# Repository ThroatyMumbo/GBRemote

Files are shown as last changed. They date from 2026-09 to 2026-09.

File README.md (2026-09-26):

# (WIP) Universal Remote cartridge for Game Boy

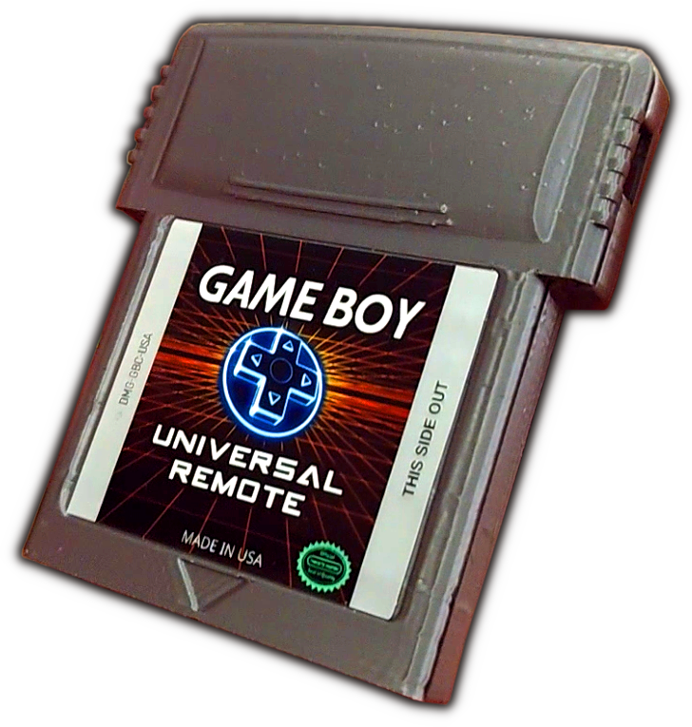
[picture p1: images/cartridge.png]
GB Universal Remote


A cartridge that lets you turn your Game Boy into many different things.
A game controller? A Bluetooth gamepad? A Bluetooth receiver? A tooth brush? Whatever your heart desires!

YouTube video: https://youtu.be/3ZZjWmHPqLs

Both the hardware and core GBC firmware is based on Shilga's Croco Cart:
- https://github.com/shilga/rp2350-gameboy-cartridge-firmware/
- https://github.com/shilga/rp-gameboy-cartridge-hw

## Building

Needs [GBDK-2020](https://github.com/gbdk-2020/gbdk-2020), the [Pico SDK](https://github.com/raspberrypi/pico-sdk) and Python 3.

```
python3 -m venv .venv && .venv/bin/pip install numpy
make -C rom GBDK_HOME=/path/to/gbdk
PICO_SDK_PATH=/path/to/pico-sdk cmake -S firmware -B firmware/build
cmake --build firmware/build
```

The first `make` builds the Game Boy ROM and embeds it in the firmware (`firmware/generated/rom.h`), so rebuild both after changing the ROM.

## Flashing

Hold the BOOTSEL button (`SW2`) while plugging the cartridge's micro-USB port into your computer, then either copy `firmware/build/gbc_controller.uf2` to the drive that appears or run:

```
picotool load -x firmware/build/gbc_controller.uf2
```

## Loading Game Boy ROMs for the Transfer Pak

The N64 driver can act as a Transfer Pak holding a Game Boy ROM stored in the cart's flash. Put the cart in BOOTSEL as above, then:

```
tools/slot.sh 1 game.gbc
```

Pick the game under Controllers → Nintendo 64 → Transfer Pak. Slots 1-6 hold up to 2 MB each and slot 7 up to 1.75 MB; loading one slot leaves the others alone. An optional third argument sets the name shown on the Game Boy.

## Screenshots

| Controller select | Gamepad | Button mapping |
|:---:|:---:|:---:|
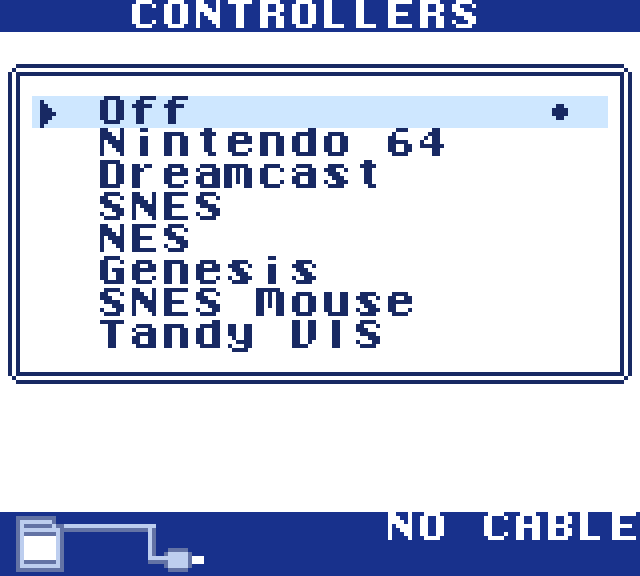
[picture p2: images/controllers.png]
Controller select
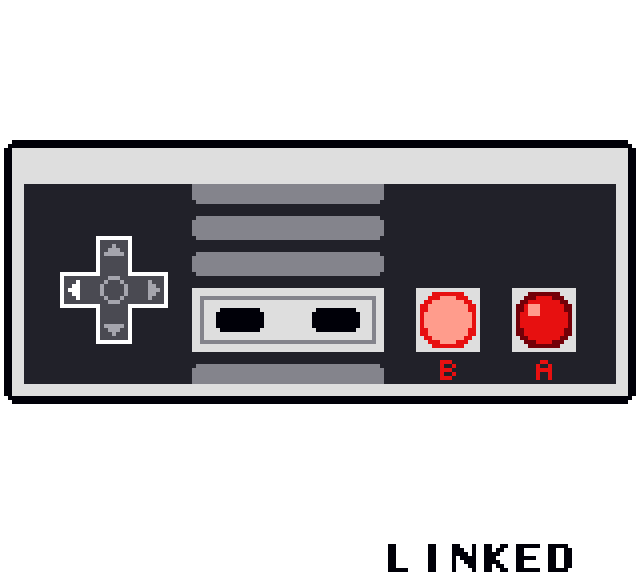
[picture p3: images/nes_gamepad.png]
NES gamepad
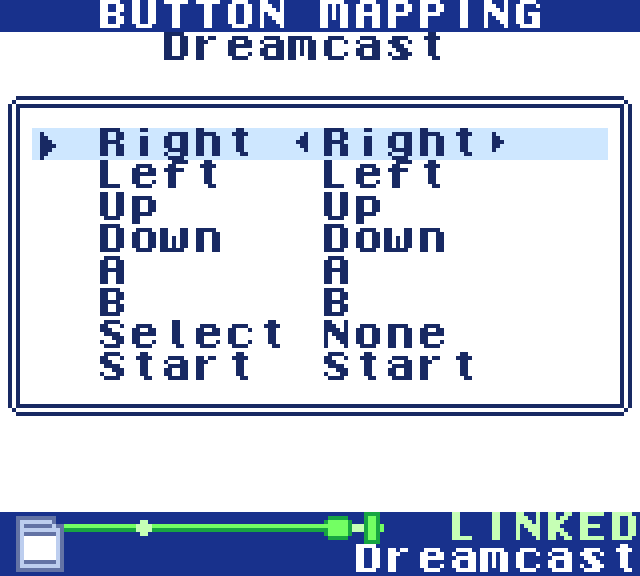
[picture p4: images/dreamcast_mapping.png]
Dreamcast button mapping
|  |  |  |
| **N64 Transfer Pak** | **Dreamcast VMU** | |
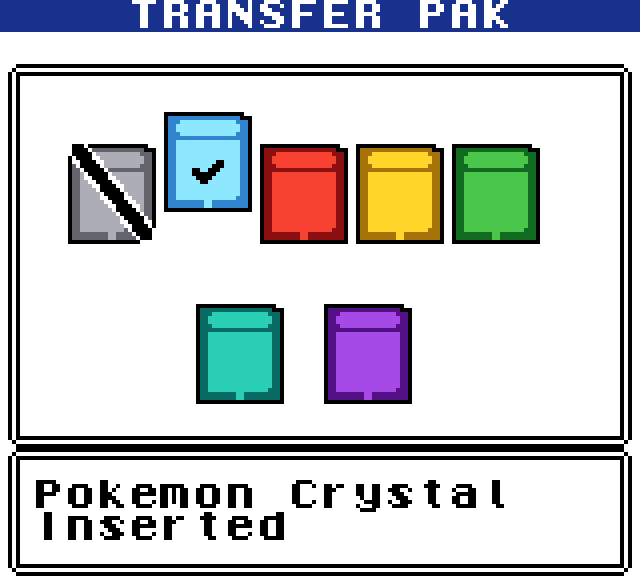
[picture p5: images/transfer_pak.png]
N64 Transfer Pak game select
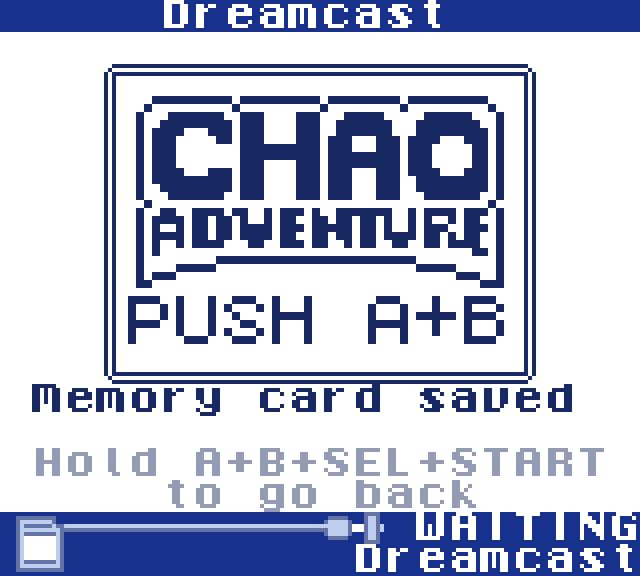
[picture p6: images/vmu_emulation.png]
Chao Adventure on the emulated VMU
|  |  | |

## FAQ

### What the hell is this?

It's a Game Boy cartridge with a bunch of stuff attached to it. USB, Bluetooth, WiFi, IR, even a generic 12-pin controller port via USB-C.

### Is this a flash cart?

Sort of. It can be used as a flash cart, although that isn't the intended purpose. It's more meant for turning a Game Boy Color into a multipurpose remote of sorts.
Plus the onboard flash is 16 MB, which is only enough for like 10 GBC games.

### Where are all those cool demos you showed in the video?

Most of them I probably won't publish since they involve modding existing commercial games, which is messy to maintain in a public repo.
However, original stuff like "Shellack!" will be published at some point when I get a chance to clean it up.

### Does this work on a regular Game Boy? What about Game Boy Advance?

- Regular Game Boy is a maybe. It doesn't physically fit, but you can cleverly bypass this using a Game Shark. However when I tried this myself it just sits on a blank screen. Haven't troubleshooted this problem.
- It does work on a Game Boy Advance

### Where do I buy this?

You can't, at least not directly. This repo contains the production files for the cartridge and adapter PCBs that you can send off to your favorite PCB manufacturing site, but I warn you it'll likely be very expensive (~$500+). Getting just two of these cartridges + 10 adapters made took a couple weeks and lots of back and forth with JLCPCB. Not to mention the tedium of wiring all those controller adapters. I wouldn't recommend it unless you have time and money to burn.

### Will you sell these at some point?

Maybe? Like every project of mine, this is really more of a novelty than something that's practically useful, so I don't see myself ordering hundreds of these and selling them on Ko-fi anytime soon. More likely a very limited run as some special merch or something.

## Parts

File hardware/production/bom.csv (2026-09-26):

Designator | Footprint | Quantity | Value | LCSC Part #
C1, C2 | 0402 | 2 | 15pF | C1548
C10, C11, C12, C13, C14, C15, C16, C17, C18, C19, C20, C21, C27, C29, C31, C32, C5, C9 | 0402 | 18 | 100nF | C1525
C22 | 1210 | 1 | 47uF | C2932478
C23, C25 | 0402 | 2 | 1uF | C52923
C24 | 0805 | 1 | 22uF | C45783
C26 | 1210 | 1 | 100uF 10V | C23742
C28 | 1206 | 1 | 47uF | C96123
C3, C4, C6, C7, C8 | 0402 | 5 | 4.7uF | C23733
C30 | 0402 | 1 | 10nF | C15195
D1, D2, D3, D9 | D_SOD-123F | 4 | SM5817PL 20V | C669022
D4, D5, D6 | SOT-23-6 | 3 | SRV05-4 | C13612
D7 | LED_Vishay_VSMB2943SL | 1 | VSMB2943SLX01 | C511094
F1 | 1206 | 1 | 500mA | C2649911
J1 | GameBoy_Cartridge_EdgeConnector | 1 | CartBus
J2 | USB_Micro-B_XKB_U254-051T-4BH83-F2S | 1 | USB micro-B device | C2682231
J3 | USB_C_Receptacle_Amphenol_12401610E4-2A | 1 | 12401610E4#2A | C5119948
J4 | JST_SH_SM06B-SRSS-TB_1x06-1MP_P1.00mm_Horizontal | 1 | DEBUG | C160405
L1 | L_Murata_DFE201610P | 1 | 3.3uH | C42411119
Q1, Q2 | SOT-23 | 2 | CJ2302 | C8548
R1, R26, R3, R31, R9 | 0402 | 5 | 1k | C11702
R10, R33 | 1206 | 2 | 0R1 | C25334
R11 | 0402 | 1 | 10R | C25077
R14, R15 | 0402 | 2 | 27R | C25100
R16, R17, R18, R19, R20, R21, R22, R23, R25 | 0402 | 9 | 100R | C25076
R2, R24, R27, R35, R4, R5, R8 | 0402 | 7 | 10k | C25744
R28 | 1206 | 1 | 22R | C17958
R29, R32 | 0402 | 2 | 100k | C25741
R30 | 0402 | 1 | 0R | C17168
R34 | 0402 | 1 | 470R | C25117
R6, R7 | 0402 | 2 | 33R | C25105
SW2 | SW_SPST_PTS810 | 1 | BOOTSEL | C116501
U1 | QFN-80-1EP_10x10mm_P0.4mm_EP3.4x3.4mm_ThermalVias | 1 | RP2350B | C42415655
U2 | SOIC-8_5.3x5.3mm_P1.27mm | 1 | W25Q128JVSIQ | C97521
U3 | SOIC-8_3.9x4.9mm_P1.27mm | 1 | APS6404L-3SQR-SN | C5333729
U4 | SOT-23-5 | 1 | AP2112K-3.3 | C51118
U5 | SOT-666 | 1 | USBLC6-2P6 | C15999
U6 | SOT-23-6 | 1 | TPS22917DBV | C2681320
U7 | RaspberryPi_RM2 | 1 | RMC20452T | C49451547
Y1 | Crystal_SMD_3225-4Pin_3.2x2.5mm | 1 | 12MHz | C20625731

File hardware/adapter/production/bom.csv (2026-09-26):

Designator | Footprint | Quantity | Value | LCSC Part #
J1 | USB_C_Plug_XUNPU_TYPEC-950-ARP24 | 1 | TYPEC-950-ARP24 | C2895017
J2 | WireTerminal_1x12_Staggered | 1 | Wire terminals

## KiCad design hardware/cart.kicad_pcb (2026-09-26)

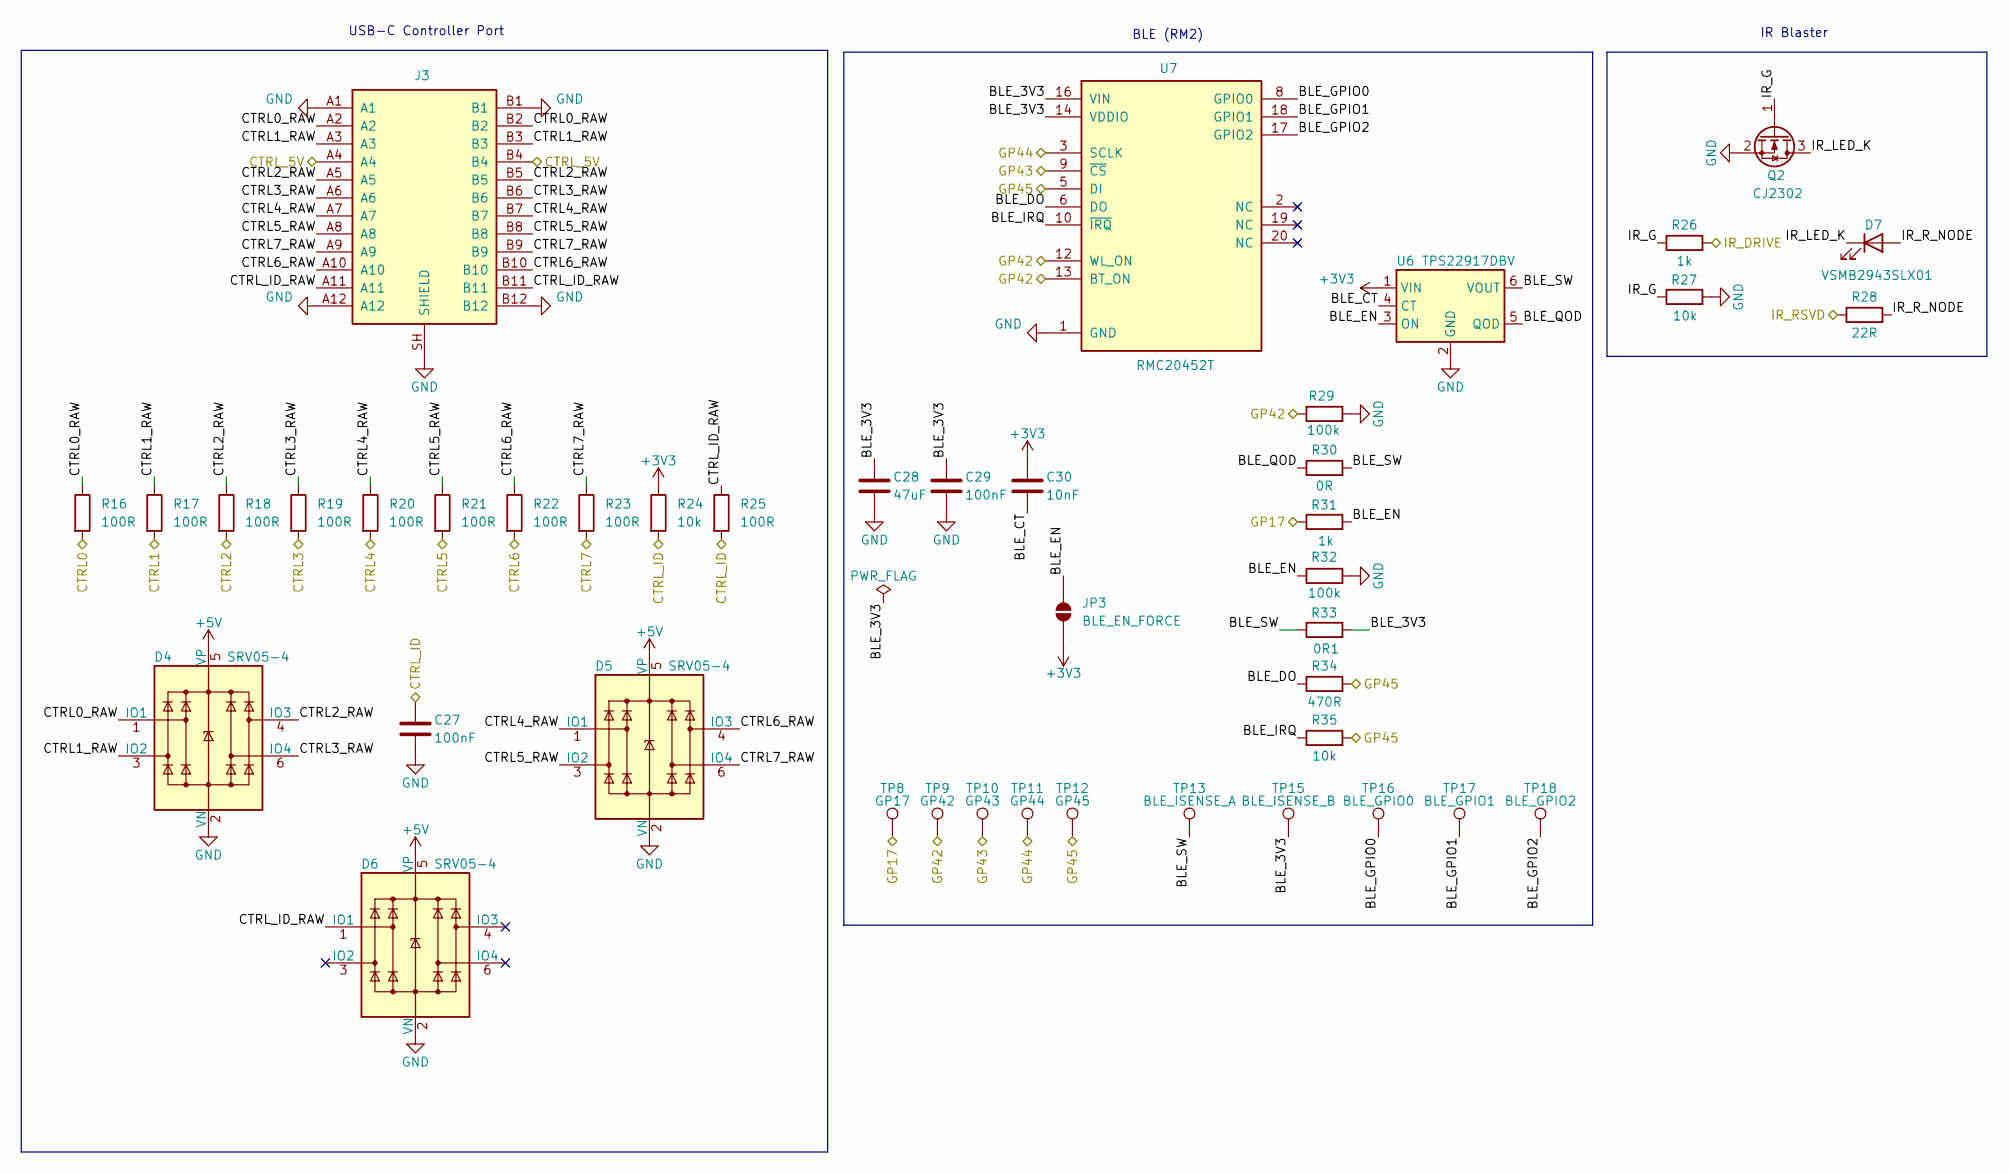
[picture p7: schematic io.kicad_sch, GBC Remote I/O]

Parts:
C27, C29: 100nF; C_0402_1005Metric; LCSC C1525
C28: 47uF; C_1206_3216Metric; LCSC C96123
C30: 10nF; C_0402_1005Metric; LCSC C15195
D4, D5, D6: SRV05-4; SOT-23-6; LCSC C13612
D7: VSMB2943SLX01; LED_Vishay_VSMB2943SL; LCSC C511094
J3: 12401610E4#2A; USB_C_Receptacle_Amphenol_12401610E4-2A; LCSC C5119948
JP3: BLE_EN_FORCE; SolderJumper-2_P1.3mm_Open_RoundedPad1.0x1.5mm
Q2: CJ2302; SOT-23; LCSC C8548
R16, R17, R18, R19, R20, R21, R22, R23, R25: 100R; R_0402_1005Metric; LCSC C25076
R24, R27, R35: 10k; R_0402_1005Metric; LCSC C25744
R26, R31: 1k; R_0402_1005Metric; LCSC C11702
R28: 22R; R_1206_3216Metric; LCSC C17958
R29, R32: 100k; R_0402_1005Metric; LCSC C25741
R30: 0R; R_0402_1005Metric; LCSC C17168
R33: 0R1; R_1206_3216Metric; LCSC C25334
R34: 470R; R_0402_1005Metric; LCSC C25117
TP8: GP17; TestPoint_Pad_D1.0mm
TP9: GP42; TestPoint_Pad_D1.0mm
TP10: GP43; TestPoint_Pad_D1.0mm
TP11: GP44; TestPoint_Pad_D1.0mm
TP12: GP45; TestPoint_Pad_D1.0mm
TP13: BLE_ISENSE_A; TestPoint_Pad_D1.0mm
TP15: BLE_ISENSE_B; TestPoint_Pad_D1.0mm
TP16: BLE_GPIO0; TestPoint_Pad_D1.0mm
TP17: BLE_GPIO1; TestPoint_Pad_D1.0mm
TP18: BLE_GPIO2; TestPoint_Pad_D1.0mm
U6: TPS22917DBV; SOT-23-6; LCSC C2681320
U7: RMC20452T; RaspberryPi_RM2; LCSC C49451547

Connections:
+3V3: C30.1, JP3.1 (A), R24.1, U6.1 (VIN); also elsewhere on the board
+5V: D4.5 (VP), D5.5 (VP), D6.5 (VP); also elsewhere on the board
/CTRL0: R16.2; also elsewhere on the board
/CTRL1: R17.2; also elsewhere on the board
/CTRL2: R18.2; also elsewhere on the board
/CTRL3: R19.2; also elsewhere on the board
/CTRL4: R20.2; also elsewhere on the board
/CTRL5: R21.2; also elsewhere on the board
/CTRL6: R22.2; also elsewhere on the board
/CTRL7: R23.2; also elsewhere on the board
/CTRL_5V: J3.A4, J3.B4; also elsewhere on the board
/CTRL_ID: C27.1, R24.2, R25.2; also elsewhere on the board
/Controller Port, IR, BLE/BLE_3V3: C28.1, C29.1, R33.2, TP15.1, U7.14 (VDDIO), U7.16 (VIN)
/Controller Port, IR, BLE/BLE_CT: C30.2, U6.4 (CT)
/Controller Port, IR, BLE/BLE_DO: R34.1, U7.6 (DO)
/Controller Port, IR, BLE/BLE_EN: JP3.2 (B), R31.2, R32.1, U6.3 (ON)
/Controller Port, IR, BLE/BLE_GPIO0: TP16.1, U7.8 (GPIO0)
/Controller Port, IR, BLE/BLE_GPIO1: TP17.1, U7.18 (GPIO1)
/Controller Port, IR, BLE/BLE_GPIO2: TP18.1, U7.17 (GPIO2)
/Controller Port, IR, BLE/BLE_IRQ: R35.1, U7.10 (~IRQ)
/Controller Port, IR, BLE/BLE_QOD: R30.1, U6.5 (QOD)
/Controller Port, IR, BLE/BLE_SW: R30.2, R33.1, TP13.1, U6.6 (VOUT)
/Controller Port, IR, BLE/CTRL0_RAW: D4.1 (IO1), J3.A2, J3.B2, R16.1
/Controller Port, IR, BLE/CTRL1_RAW: D4.3 (IO2), J3.A3, J3.B3, R17.1
/Controller Port, IR, BLE/CTRL2_RAW: D4.4 (IO3), J3.A5, J3.B5, R18.1
/Controller Port, IR, BLE/CTRL3_RAW: D4.6 (IO4), J3.A6, J3.B6, R19.1
/Controller Port, IR, BLE/CTRL4_RAW: D5.1 (IO1), J3.A7, J3.B7, R20.1
/Controller Port, IR, BLE/CTRL5_RAW: D5.3 (IO2), J3.A8, J3.B8, R21.1
/Controller Port, IR, BLE/CTRL6_RAW: D5.4 (IO3), J3.A10, J3.B10, R22.1
/Controller Port, IR, BLE/CTRL7_RAW: D5.6 (IO4), J3.A9, J3.B9, R23.1
/Controller Port, IR, BLE/CTRL_ID_RAW: D6.1 (IO1), J3.A11, J3.B11, R25.1
/Controller Port, IR, BLE/IR_G: Q2.1 (G), R26.1, R27.1
/Controller Port, IR, BLE/IR_LED_K: D7.1 (K), Q2.3 (D)
/Controller Port, IR, BLE/IR_R_NODE: D7.2 (A), R28.2
/GP17: R31.1, TP8.1; also elsewhere on the board
/GP42: R29.1, TP9.1, U7.12 (WL_ON), U7.13 (BT_ON); also elsewhere on the board
/GP43: TP10.1, U7.9 (~CS); also elsewhere on the board
/GP44: TP11.1, U7.3 (SCLK); also elsewhere on the board
/GP45: R34.2, R35.2, TP12.1, U7.5 (DI); also elsewhere on the board
/IR_DRIVE: R26.2; also elsewhere on the board
/IR_RSVD: R28.1; also elsewhere on the board
GND: C27.2, C28.2, C29.2, D4.2 (VN), D5.2 (VN), D6.2 (VN), J3.A1, J3.A12, J3.B1, J3.B12, J3.SH (SHIELD), Q2.2 (S), R27.2, R29.2, R32.2, U6.2 (GND), U7.1 (GND), U7.4 (GND), U7.7 (GND), U7.11 (GND), U7.15 (GND), U7.21 (GND); also elsewhere on the board

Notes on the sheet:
IR Blaster
BLE (RM2)
USB-C Controller Port

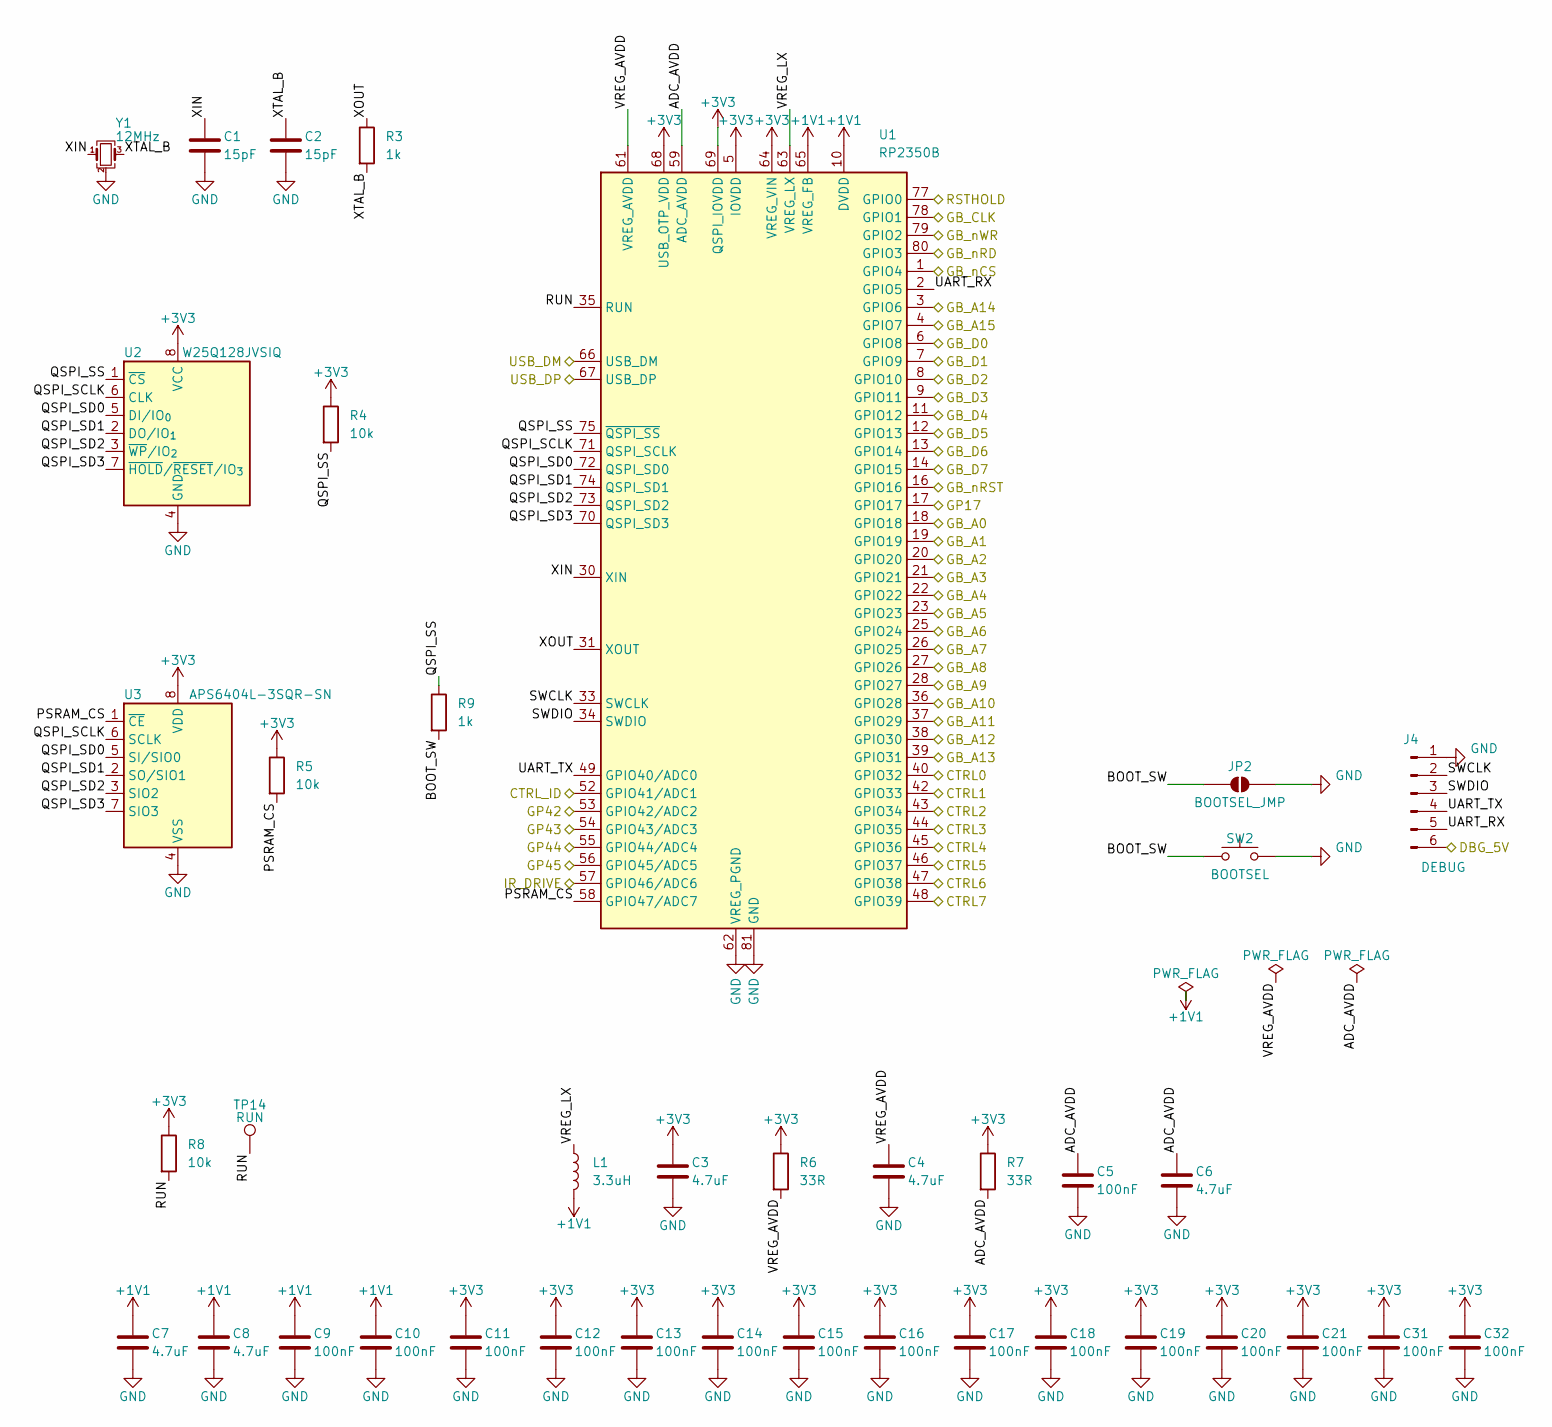
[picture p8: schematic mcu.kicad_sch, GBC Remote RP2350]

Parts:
C1, C2: 15pF; C_0402_1005Metric; LCSC C1548
C3, C4, C6, C7, C8: 4.7uF; C_0402_1005Metric; LCSC C23733
C5, C9, C10, C11, C12, C13, C14, C15, C16, C17, C18, C19, C20, C21, C31, C32: 100nF; C_0402_1005Metric; LCSC C1525
J4: DEBUG; JST_SH_SM06B-SRSS-TB_1x06-1MP_P1.00mm_Horizontal; LCSC C160405
JP2: BOOTSEL_JMP; SolderJumper-2_P1.3mm_Open_RoundedPad1.0x1.5mm
L1: 3.3uH; L_Murata_DFE201610P; LCSC C42411119
R3, R9: 1k; R_0402_1005Metric; LCSC C11702
R4, R5, R8: 10k; R_0402_1005Metric; LCSC C25744
R6, R7: 33R; R_0402_1005Metric; LCSC C25105
SW2: BOOTSEL; SW_SPST_PTS810; LCSC C116501
TP14: RUN; TestPoint_Pad_D1.0mm
U1: RP2350B; QFN-80-1EP_10x10mm_P0.4mm_EP3.4x3.4mm_ThermalVias; LCSC C42415655
U2: W25Q128JVSIQ; SOIC-8_5.3x5.3mm_P1.27mm; LCSC C97521
U3: APS6404L-3SQR-SN; SOIC-8_3.9x4.9mm_P1.27mm; LCSC C5333729
Y1: 12MHz; Crystal_SMD_3225-4Pin_3.2x2.5mm; LCSC C20625731

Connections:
+1V1: C7.1, C8.1, C9.1, C10.1, L1.2, U1.10 (DVDD), U1.32 (DVDD), U1.51 (DVDD), U1.65 (VREG_FB); also elsewhere on the board
+3V3: C3.1, C11.1, C12.1, C13.1, C14.1, C15.1, C16.1, C17.1, C18.1, C19.1, C20.1, C21.1, C31.1, C32.1, R4.1, R5.1, R6.1, R7.1, R8.1, U1.5 (IOVDD), U1.15 (IOVDD), U1.24 (IOVDD), U1.29 (IOVDD), U1.41 (IOVDD), U1.50 (IOVDD), U1.60 (IOVDD), U1.64 (VREG_VIN), U1.68 (USB_OTP_VDD), U1.69 (QSPI_IOVDD), U1.76 (IOVDD), U2.8 (VCC), U3.8 (VDD); also elsewhere on the board
/CTRL0: U1.40 (GPIO32); also elsewhere on the board
/CTRL1: U1.42 (GPIO33); also elsewhere on the board
/CTRL2: U1.43 (GPIO34); also elsewhere on the board
/CTRL3: U1.44 (GPIO35); also elsewhere on the board
/CTRL4: U1.45 (GPIO36); also elsewhere on the board
/CTRL5: U1.46 (GPIO37); also elsewhere on the board
/CTRL6: U1.47 (GPIO38); also elsewhere on the board
/CTRL7: U1.48 (GPIO39); also elsewhere on the board
/CTRL_ID: U1.52 (GPIO41/ADC1); also elsewhere on the board
/DBG_5V: J4.6; also elsewhere on the board
/GB_A0: U1.18 (GPIO18); also elsewhere on the board
/GB_A1: U1.19 (GPIO19); also elsewhere on the board
/GB_A2: U1.20 (GPIO20); also elsewhere on the board
/GB_A3: U1.21 (GPIO21); also elsewhere on the board
/GB_A4: U1.22 (GPIO22); also elsewhere on the board
/GB_A5: U1.23 (GPIO23); also elsewhere on the board
/GB_A6: U1.25 (GPIO24); also elsewhere on the board
/GB_A7: U1.26 (GPIO25); also elsewhere on the board
/GB_A8: U1.27 (GPIO26); also elsewhere on the board
/GB_A9: U1.28 (GPIO27); also elsewhere on the board
/GB_A10: U1.36 (GPIO28); also elsewhere on the board
/GB_A11: U1.37 (GPIO29); also elsewhere on the board
/GB_A12: U1.38 (GPIO30); also elsewhere on the board
/GB_A13: U1.39 (GPIO31); also elsewhere on the board
/GB_A14: U1.3 (GPIO6); also elsewhere on the board
/GB_A15: U1.4 (GPIO7); also elsewhere on the board
/GB_CLK: U1.78 (GPIO1); also elsewhere on the board
/GB_D0: U1.6 (GPIO8); also elsewhere on the board
/GB_D1: U1.7 (GPIO9); also elsewhere on the board
/GB_D2: U1.8 (GPIO10); also elsewhere on the board
/GB_D3: U1.9 (GPIO11); also elsewhere on the board
/GB_D4: U1.11 (GPIO12); also elsewhere on the board
/GB_D5: U1.12 (GPIO13); also elsewhere on the board
/GB_D6: U1.13 (GPIO14); also elsewhere on the board
/GB_D7: U1.14 (GPIO15); also elsewhere on the board
/GB_nCS: U1.1 (GPIO4); also elsewhere on the board
/GB_nRD: U1.80 (GPIO3); also elsewhere on the board
/GB_nRST: U1.16 (GPIO16); also elsewhere on the board
/GB_nWR: U1.79 (GPIO2); also elsewhere on the board
/GP17: U1.17 (GPIO17); also elsewhere on the board
/GP42: U1.53 (GPIO42/ADC2); also elsewhere on the board
/GP43: U1.54 (GPIO43/ADC3); also elsewhere on the board
/GP44: U1.55 (GPIO44/ADC4); also elsewhere on the board
/GP45: U1.56 (GPIO45/ADC5); also elsewhere on the board
/IR_DRIVE: U1.57 (GPIO46/ADC6); also elsewhere on the board
/MCU/ADC_AVDD: C5.1, C6.1, R7.2, U1.59 (ADC_AVDD)
/MCU/BOOT_SW: JP2.1 (A), R9.2, SW2.1
/MCU/PSRAM_CS: R5.2, U1.58 (GPIO47/ADC7), U3.1 (~CE)
/MCU/QSPI_SCLK: U1.71 (QSPI_SCLK), U2.6 (CLK), U3.6 (SCLK)
/MCU/QSPI_SD0: U1.72 (QSPI_SD0), U2.5 (DI/IO_{0}), U3.5 (SI/SIO0)
/MCU/QSPI_SD1: U1.74 (QSPI_SD1), U2.2 (DO/IO_{1}), U3.2 (SO/SIO1)
/MCU/QSPI_SD2: U1.73 (QSPI_SD2), U2.3 (~WP/IO_{2}), U3.3 (SIO2)
/MCU/QSPI_SD3: U1.70 (QSPI_SD3), U2.7 (~HOLD/~RESET/IO_{3}), U3.7 (SIO3)
/MCU/QSPI_SS: R4.2, R9.1, U1.75 (~QSPI_SS), U2.1 (~CS)
/MCU/RUN: R8.2, TP14.1, U1.35 (RUN)
/MCU/SWCLK: J4.2, U1.33 (SWCLK)
/MCU/SWDIO: J4.3, U1.34 (SWDIO)
/MCU/UART_RX: J4.5, U1.2 (GPIO5)
/MCU/UART_TX: J4.4, U1.49 (GPIO40/ADC0)
/MCU/VREG_AVDD: C4.1, R6.2, U1.61 (VREG_AVDD)
/MCU/VREG_LX: L1.1, U1.63 (VREG_LX)
/MCU/XIN: C1.1, U1.30 (XIN), Y1.1
/MCU/XOUT: R3.1, U1.31 (XOUT)
/MCU/XTAL_B: C2.1, R3.2, Y1.3
/RSTHOLD: U1.77 (GPIO0); also elsewhere on the board
/USB_DM: U1.66 (USB_DM); also elsewhere on the board
/USB_DP: U1.67 (USB_DP); also elsewhere on the board
GND: C1.2, C2.2, C3.2, C4.2, C5.2, C6.2, C7.2, C8.2, C9.2, C10.2, C11.2, C12.2, C13.2, C14.2, C15.2, C16.2, C17.2, C18.2, C19.2, C20.2, C21.2, C31.2, C32.2, J4.1, JP2.2 (B), SW2.2, U1.62 (VREG_PGND), U1.81 (GND), U2.4 (GND), U3.4 (VSS), Y1.2 (G), Y1.4 (G); also elsewhere on the board

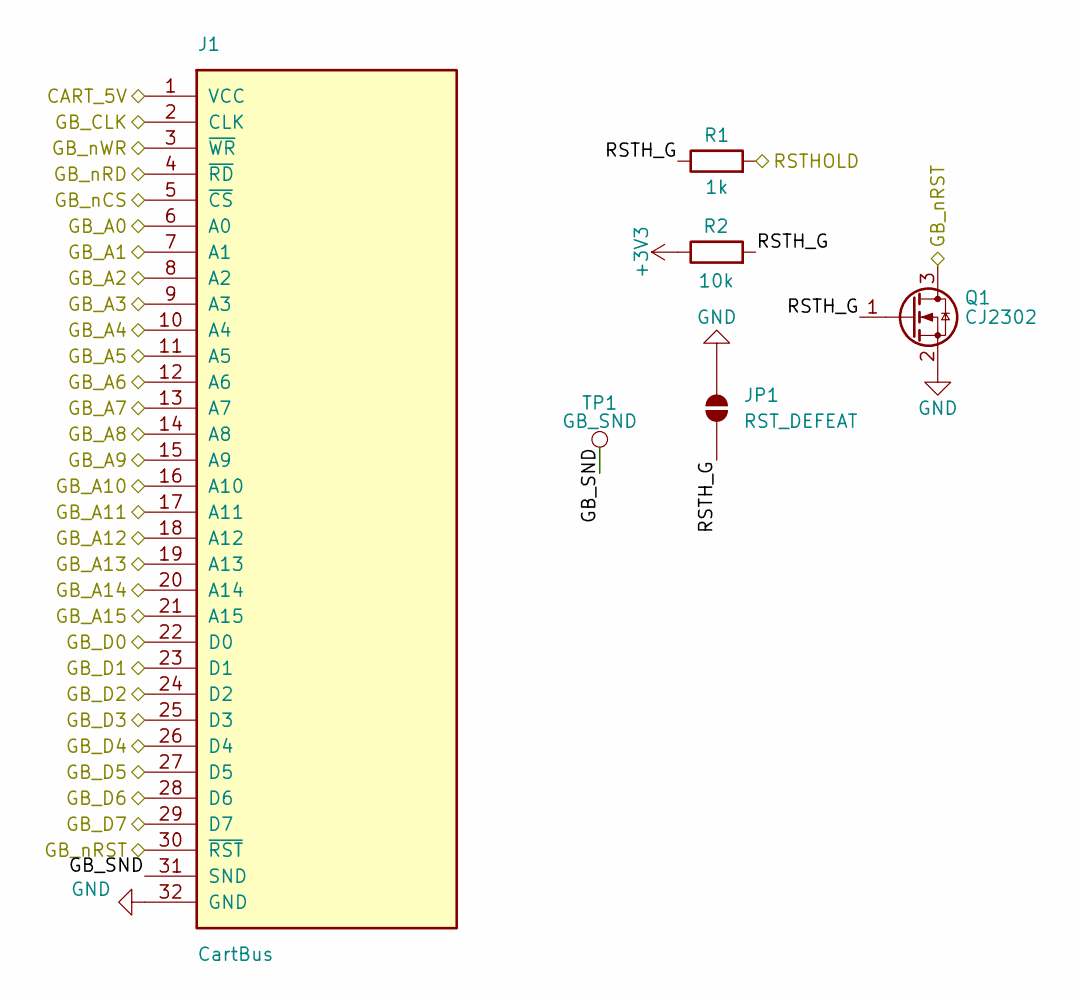
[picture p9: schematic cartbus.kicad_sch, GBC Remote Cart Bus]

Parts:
J1: CartBus; GameBoy_Cartridge_EdgeConnector
JP1: RST_DEFEAT; SolderJumper-2_P1.3mm_Open_RoundedPad1.0x1.5mm
Q1: CJ2302; SOT-23; LCSC C8548
R1: 1k; R_0402_1005Metric; LCSC C11702
R2: 10k; R_0402_1005Metric; LCSC C25744
TP1: GB_SND; TestPoint_Pad_D1.0mm

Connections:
+3V3: R2.1; also elsewhere on the board
/CART_5V: J1.1 (VCC); also elsewhere on the board
/Cart Bus/GB_SND: J1.31 (SND), TP1.1
/Cart Bus/RSTH_G: JP1.1 (A), Q1.1 (G), R1.1, R2.2
/GB_A0: J1.6 (A0); also elsewhere on the board
/GB_A1: J1.7 (A1); also elsewhere on the board
/GB_A2: J1.8 (A2); also elsewhere on the board
/GB_A3: J1.9 (A3); also elsewhere on the board
/GB_A4: J1.10 (A4); also elsewhere on the board
/GB_A5: J1.11 (A5); also elsewhere on the board
/GB_A6: J1.12 (A6); also elsewhere on the board
/GB_A7: J1.13 (A7); also elsewhere on the board
/GB_A8: J1.14 (A8); also elsewhere on the board
/GB_A9: J1.15 (A9); also elsewhere on the board
/GB_A10: J1.16 (A10); also elsewhere on the board
/GB_A11: J1.17 (A11); also elsewhere on the board
/GB_A12: J1.18 (A12); also elsewhere on the board
/GB_A13: J1.19 (A13); also elsewhere on the board
/GB_A14: J1.20 (A14); also elsewhere on the board
/GB_A15: J1.21 (A15); also elsewhere on the board
/GB_CLK: J1.2 (CLK); also elsewhere on the board
/GB_D0: J1.22 (D0); also elsewhere on the board
/GB_D1: J1.23 (D1); also elsewhere on the board
/GB_D2: J1.24 (D2); also elsewhere on the board
/GB_D3: J1.25 (D3); also elsewhere on the board
/GB_D4: J1.26 (D4); also elsewhere on the board
/GB_D5: J1.27 (D5); also elsewhere on the board
/GB_D6: J1.28 (D6); also elsewhere on the board
/GB_D7: J1.29 (D7); also elsewhere on the board
/GB_nCS: J1.5 (~CS); also elsewhere on the board
/GB_nRD: J1.4 (~RD); also elsewhere on the board
/GB_nRST: J1.30 (~RST), Q1.3 (D); also elsewhere on the board
/GB_nWR: J1.3 (~WR); also elsewhere on the board
/RSTHOLD: R1.2; also elsewhere on the board
GND: J1.32 (GND), JP1.2 (B), Q1.2 (S); also elsewhere on the board

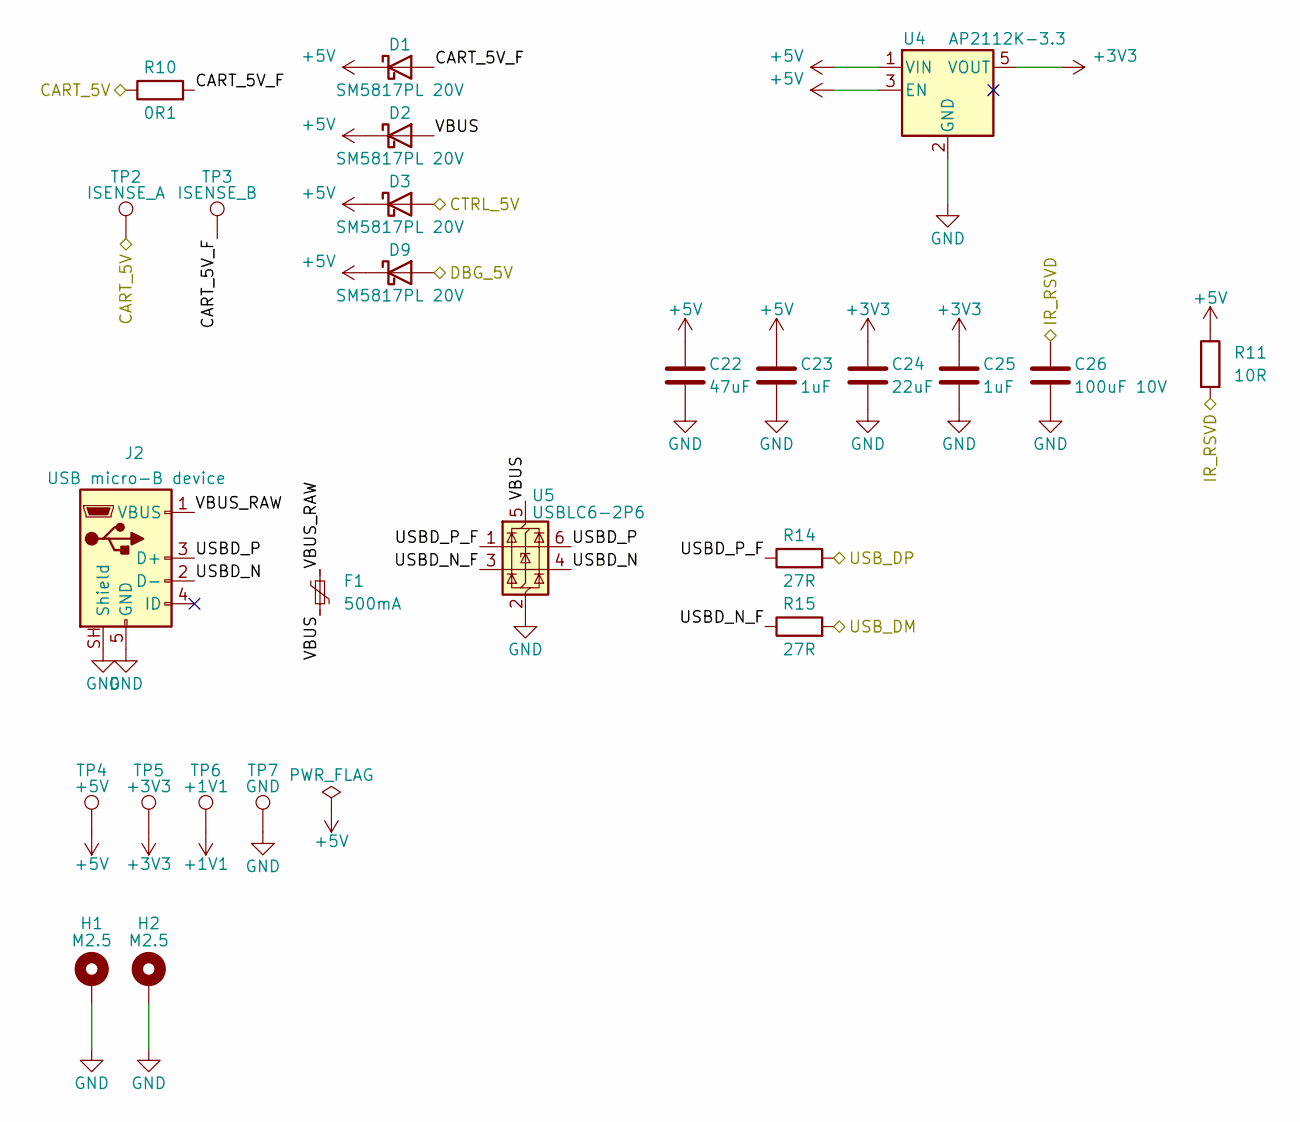
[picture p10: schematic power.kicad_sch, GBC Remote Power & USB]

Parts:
C22: 47uF; C_1210_3225Metric; LCSC C2932478
C23, C25: 1uF; C_0402_1005Metric; LCSC C52923
C24: 22uF; C_0805_2012Metric; LCSC C45783
C26: 100uF 10V; C_1210_3225Metric; LCSC C23742
D1, D2, D3, D9: SM5817PL 20V; D_SOD-123F; LCSC C669022
F1: 500mA; Fuse_1206_3216Metric; LCSC C2649911
H1, H2: M2.5; MountingHole_2.7mm_M2.5_Pad
J2: USB micro-B device; USB_Micro-B_XKB_U254-051T-4BH83-F2S; LCSC C2682231
R10: 0R1; R_1206_3216Metric; LCSC C25334
R11: 10R; R_0402_1005Metric; LCSC C25077
R14, R15: 27R; R_0402_1005Metric; LCSC C25100
TP2: ISENSE_A; TestPoint_Pad_D1.0mm
TP3: ISENSE_B; TestPoint_Pad_D1.0mm
TP4: +5V; TestPoint_Pad_D1.0mm
TP5: +3V3; TestPoint_Pad_D1.0mm
TP6: +1V1; TestPoint_Pad_D1.0mm
TP7: GND; TestPoint_Pad_D1.0mm
U4: AP2112K-3.3; SOT-23-5; LCSC C51118
U5: USBLC6-2P6; SOT-666; LCSC C15999

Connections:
+1V1: TP6.1; also elsewhere on the board
+3V3: C24.1, C25.1, TP5.1, U4.5 (VOUT); also elsewhere on the board
+5V: C22.1, C23.1, D1.1 (K), D2.1 (K), D3.1 (K), D9.1 (K), R11.1, TP4.1, U4.1 (VIN), U4.3 (EN); also elsewhere on the board
/CART_5V: R10.1, TP2.1; also elsewhere on the board
/CTRL_5V: D3.2 (A); also elsewhere on the board
/DBG_5V: D9.2 (A); also elsewhere on the board
/IR_RSVD: C26.1, R11.2; also elsewhere on the board
/Power and USB/CART_5V_F: D1.2 (A), R10.2, TP3.1
/Power and USB/USBD_N: J2.2 (D-), U5.4 (I/O2)
/Power and USB/USBD_N_F: R15.1, U5.3 (I/O2)
/Power and USB/USBD_P: J2.3 (D+), U5.6 (I/O1)
/Power and USB/USBD_P_F: R14.1, U5.1 (I/O1)
/Power and USB/VBUS: D2.2 (A), F1.2, U5.5 (VBUS)
/Power and USB/VBUS_RAW: F1.1, J2.1 (VBUS)
/USB_DM: R15.2; also elsewhere on the board
/USB_DP: R14.2; also elsewhere on the board
GND: C22.2, C23.2, C24.2, C25.2, C26.2, H1.1, H2.1, J2.5 (GND), J2.SH (Shield), TP7.1, U4.2 (GND), U5.2 (GND); also elsewhere on the board

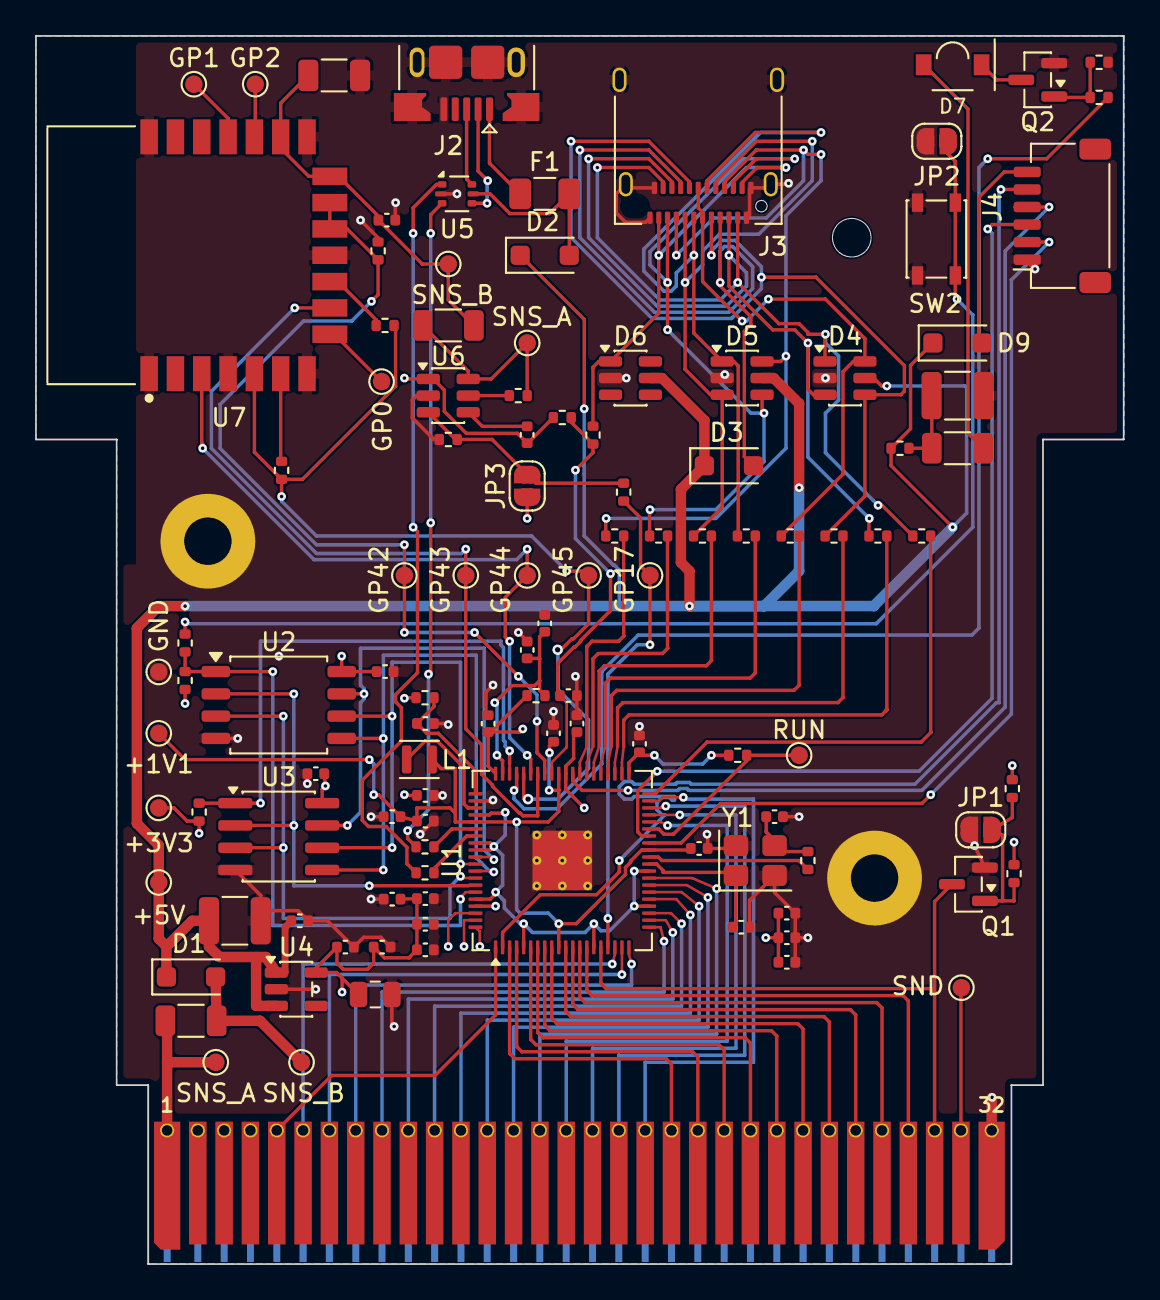
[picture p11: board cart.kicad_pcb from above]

Board: 4 copper layers, 62.0 x 70.0 mm, 113 parts (0 on the bottom side), 105 nets.

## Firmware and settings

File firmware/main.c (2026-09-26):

// GBC controller cart: serves the menu ROM from SRAM (cartserve.c), decodes the cart-bus mailbox on
// core0 in run_bus(), and runs the resident pad driver on core1 (driver_core.c).

#include "pico/stdlib.h"
#include "hardware/clocks.h"
#include "hardware/pio.h"
#include "hardware/flash.h"
#include "hardware/sync.h"
#include "hardware/structs/sio.h"
#include "hardware/timer.h"
#include <stdio.h>
#include <string.h>

#include "pinmap.h"
#include "cartserve.h"
#include "psram.h"
#include "rom.h"                // generated by run.sh: gb_rom[GB_ROM_BANKS][16384], in flash
#include "cart_mbc.h"
#include "config_map.h"
#include "ctrl.h"
#include "cable_id.h"
#include "driver_core.h"
#include "pad_catalog.h"
#include "pad_mapinfo.h"
#include "romstore.h"
#include "vmu_stage.h"
#include "vmu_store.h"
#include "vmu_run.h"
#include "vmu_fb.h"
#include "padart.h"
#include "flash_burn.h"

#define FW_VERSION 1

_Static_assert(GB_ROM_BANKS >= 2 && GB_ROM_BANKS <= 16, "every bank is resident: 2-16 banks");

// Banks 0 and 1 are cartserve's own: cs_seed() lands in 0, and 1 is the VMU/art window.
static uint8_t __attribute__((aligned(0x4000))) g_banks[GB_ROM_BANKS > 2 ? GB_ROM_BANKS - 2 : 1][0x4000];
static uint8_t *g_bank_ptr[GB_ROM_BANKS];

// GB -> firmware: writes to $6000+n, n from A0-A2, latched for free by write_capture.
#define MBOX_REGION   0x6000
enum { MBOX_BTN = 0, MBOX_MODE = 1, MBOX_CFG_IDX = 2, MBOX_CFG_VAL = 3, MBOX_COMMIT = 4 };

// firmware -> GB: plain bytes of the served bank 0, rewritten under the console.
#define STATUS_ADDR    0x0010
#define VERSION_ADDR   0x0011
#define ID_ADDR        0x0012   // adapter slot from the cable ID ladder (ADAPT_*)
#define DIAG_ADDR      0x0013   // driver error code, so the ROM can say why nothing is driven
// The PROTO_SEL echo is no proof a driver started; these are what core1 owns and when it acted.
#define ACTIVE_ADDR    0x0014   // PROTO_* of the resident driver, PROTO_NONE if nothing is driven
#define APPLYSEQ_ADDR  0x0015   // low byte of the drv_apply() counter
// The Visual Memory. SEQ is bumped after a whole frame is in place, so the ROM never blits mid-write.
#define VMU_SEQ_ADDR   0x0016
#define VMU_STAT_ADDR  0x0017
#define VMU_SAVES_ADDR 0x0018
// The controller picture staged at $4600 (padart.h). PROTO says whose it is, SEQ that it is whole.
#define ART_SEQ_ADDR   0x0019
#define ART_PROTO_ADDR 0x001a
// pad.h's PAD_* bits 0-23 after map_apply(), low byte first: what core1 drives, not what the GB pressed.
#define PAD_LIVE_ADDR  0x001b
#define PAD_LIVE_SEQ   0x001e   // poked last; the three data bytes are separate pokes and can tear

#define VMU_ST_CARD    0x01     // a card is live
#define VMU_ST_DIRTY   0x02     // writes the flash copy does not have yet
#define VMU_ST_SAVING  0x04     // a writeback is in flight
#define VMU_ST_FRAME   0x08     // the console has drawn to the LCD this session
#define CFG_MIRROR     0x0200   // CFG_LEN bytes, config_map.h
#define CATALOG_ADDR   0x0300   // driver catalog, pad_catalog.h. Seeded once at boot, never rewritten.

#define ST_ALIVE       0x01     // firmware up and serving
#define ST_LINK_UP     0x02     // transport connected
#define ST_FORCE_CFG   0x80     // escape hatch: ROM must leave capture mode

enum { MODE_CONFIG = 0, MODE_CAPTURE = 1 };

static uint8_t  g_config[CFG_LEN];
static volatile uint8_t  g_buttons, g_mode, g_status = ST_ALIVE;
static volatile uint8_t  g_cfg_idx, g_cfg_class, g_adapter, g_diag, g_active, g_aseq;
static volatile bool     g_cfg_dirty, g_commit_req, g_btn_pending;
static volatile uint32_t g_btn_seq, g_wr_count, g_mbox_writes, g_gb_runs;
static uint32_t g_ps_size;


static void publish_status(void) { cs_poke(STATUS_ADDR, g_status); }

static uint8_t g_vmu_stat = VMU_ST_CARD, g_vmu_saves;

// On change, like ACTIVE/APPLYSEQ: the ROM polls these every pass and a poke costs a bus cycle.
static void publish_vmu(void) {
    const vmu_stage_t *s = vmu_stage();
    uint8_t st = (uint8_t)(VMU_ST_CARD
                 | (s->writes != s->saved_writes ? VMU_ST_DIRTY : 0)
                 | (vmu_store_busy() ? VMU_ST_SAVING : 0)
                 | (s->lcd_frames ? VMU_ST_FRAME : 0));

    if (st != g_vmu_stat)              { g_vmu_stat = st;  cs_poke(VMU_STAT_ADDR, st); }
    if ((uint8_t)s->saves != g_vmu_saves) {
        g_vmu_saves = (uint8_t)s->saves;
        cs_poke(VMU_SAVES_ADDR, g_vmu_saves);
    }
}

// On change only, like publish_vmu(): a poke costs a bus cycle and the ROM polls these every pass.
static uint32_t g_pad_live = 0xffffffffU;
static uint8_t  g_pad_live_seq;

static void publish_pad_live(void) {
    uint32_t b = drv_pad_live() & 0xffffffU;
    if (b == g_pad_live) { return; }
    for (unsigned i = 0; i < 3; i++) {
        if (((b ^ g_pad_live) >> (8 * i)) & 0xffU) {
            cs_poke((uint16_t)(PAD_LIVE_ADDR + i), (uint8_t)(b >> (8 * i)));
        }
    }
    g_pad_live = b;
    cs_poke(PAD_LIVE_SEQ, ++g_pad_live_seq);            // after the data, always
}

static void publish_config(void) {
    for (uint32_t i = 0; i < CFG_LEN; i++) { cs_poke(CFG_MIRROR + i, g_config[i]); }
}

// A known cable overrides the selected protocol in g_config itself, so the mirror tells the menu.
static bool cable_select(void) {
#ifdef BENCH_PROTO
    return false;
#else
    uint8_t p = cable_id_proto(g_adapter, g_config[CFG_PROTO_SEL]);
    if (p == g_config[CFG_PROTO_SEL]) { return false; }
    g_config[CFG_PROTO_SEL] = p;
    return true;
#endif
}

// Config lives in the last flash sector. Erasing it live stalls core0, never the SRAM serve path.
#define CFG_FLASH_OFF (PICO_FLASH_SIZE_BYTES - FLASH_SECTOR_SIZE)
#define CFG_MAGIC     0x43474243u
#define CFG_PAGE      (2 * FLASH_PAGE_SIZE)   // magic + CFG_LEN rounded up to a programmable multiple

static void config_load(void) {
    const uint8_t *p = (const uint8_t *)(XIP_BASE + CFG_FLASH_OFF);
    uint32_t magic;
    memcpy(&magic, p, sizeof magic);
    if (magic == CFG_MAGIC) {
        memcpy(g_config, p + 4, CFG_LEN);
    } else {
        memset(g_config, 0xff, CFG_LEN);
    }
}

// core0 only. The erase runs with only core0's interrupts masked, which is safe solely because the
// binary is copy_to_ram and core1 never touches flash, XIP or PSRAM (see pad_driver.h).
static void config_save(void) {
    hard_assert(get_core_num() == 0);
    static uint8_t page[CFG_PAGE];
    uint32_t magic = CFG_MAGIC;
    memset(page, 0xff, sizeof page);
    memcpy(page, &magic, sizeof magic);
    memcpy(page + 4, g_config, CFG_LEN);
    flash_burn(CFG_FLASH_OFF, FLASH_SECTOR_SIZE, page, CFG_PAGE);
}

// Every config change lands here: the menu's mirror, the Transfer Pak slot, then core1.
static void reconfig(uint8_t cls, uint32_t now) {
    publish_config();
    romstore_config(g_config);
    drv_config_changed(g_config, cls, now);
}

#ifdef BENCH_PROTO
static const char k_bench_keys[] = "dawsjknm";   // GB bit order: R L U D A B SELECT START
static uint8_t  g_inject;
static uint32_t g_inject_ms;
static uint8_t  g_bench_slot;   // bench 'g': the Transfer Pak slot the GB menu would have written

void snes_bench_force(uint32_t w, bool on);                     // drivers/snes.c, bench only
void gen_bench_force(uint32_t dpad, uint32_t tltr, bool on);    // drivers/genesis.c, bench only
void gen_bench_stats(uint32_t *polls, uint32_t *resyncs, uint32_t *drops);
void n64_bench_report(void);                                    // drivers/n64.c, bench only
void n64_trace_dump(void);                                      // drivers/n64.c, bench only
void dc_trace_dump(void);                                       // drivers/dc.c, bench only
void maple_vmu_read_cap(unsigned bytes);                        // drivers/maple_proto.c, bench only
static int g_force_bit = -1;

// Bench ']': drive one wire position at a time, bypassing the pad mapping, so the console names
// the bit it perceives. Width and names are per protocol — one shared table would mislabel them.
static void bench_force(int bit) {
    if (g_config[CFG_PROTO_SEL] == PROTO_GENESIS) {
        static const char *k_gen[] = { "D0 UP/Z", "D1 DOWN/Y", "D2 LEFT/X", "D3 RIGHT/MODE",
                                       "TL B/A", "TR C/START", "TL+TR", "all six" };
        // A line held low through every cycle AND both TH halves, so it reads the same wherever
        // the ROM looks and whatever level a disconnected TH happens to float at.
        static const uint8_t k_tt[] = { 0, 0, 0, 0, 0x5, 0xa, 0xf, 0xf };
        uint32_t dp = (bit >= 0 && bit < 4) ? 0x11111111u << bit
                    : (bit == 7)            ? 0xffffffffu : 0;
        uint32_t tt = (bit >= 0) ? k_tt[bit] : 0;
        gen_bench_force(dp, tt, bit >= 0);
        if (bit < 0) printf("force: OFF\n");
        else         printf("force: bit %d = %s  dpad=%08lx tltr=%02lx\n", bit, k_gen[bit],
                            (unsigned long)dp, (unsigned long)tt);
        return;
    }
    static const char *k_snes[16] = { "B", "Y", "SELECT", "START", "UP", "DOWN", "LEFT",
                                      "RIGHT", "A", "X", "L", "R", "id12", "id13",
                                      "id14", "id15" };
    snes_bench_force(bit < 0 ? 0 : 1u << bit, bit >= 0);
    if (bit < 0) printf("force: OFF\n");
    else         printf("force: bit %d = %s\n", bit, k_snes[bit]);
}

static int bench_force_bits(void) {
    return g_config[CFG_PROTO_SEL] == PROTO_GENESIS ? 8 : 16;
}

// Bench 'p': edge census on CTRL0-7 over 200 ms. Input reads only, so it cannot disturb the pins
// core1's driver owns. gpio_hi_in bit 0 is GP32; gpio_get() does not reach GP32+.
static void __not_in_flash_func(ctrl_census)(void) {
    uint32_t edges[PIN_CTRL_N] = { 0 };
    uint32_t prev = sio_hw->gpio_hi_in, n = 0;
    uint32_t t0 = timer_hw->timerawl;
    while (timer_hw->timerawl - t0 < 200000u) {
        uint32_t cur = sio_hw->gpio_hi_in, ch = cur ^ prev;
        for (uint i = 0; i < PIN_CTRL_N; i++)
            if (ch & (1u << (PIN_CTRL0 - 32 + i))) edges[i]++;
        prev = cur;
        n++;
    }
    printf("census 200ms samples=%lu", (unsigned long)n);
    for (uint i = 0; i < PIN_CTRL_N; i++)
        printf(" GP%u=%lu/%u", PIN_CTRL0 + i, (unsigned long)edges[i],
               (unsigned)((prev >> (PIN_CTRL0 - 32 + i)) & 1u));
    printf("\n");
}

// Bench 't': timestamped edge trace of CTRL0-7 over two frames, to order line moves against TH.
#define TRACE_N 224
static uint32_t g_tr_st[TRACE_N], g_tr_ts[TRACE_N];
static void __not_in_flash_func(port_trace)(void) {
    uint32_t mask = 0xffu << (PIN_CTRL0 - 32), n = 0;
    uint32_t save = save_and_disable_interrupts();
    uint32_t prev = sio_hw->gpio_hi_in & mask;
    uint32_t t0 = timer_hw->timerawl;
    while (timer_hw->timerawl - t0 < 50000u && (sio_hw->gpio_hi_in & mask) == prev) { }
    t0 = timer_hw->timerawl;
    while (n < TRACE_N && timer_hw->timerawl - t0 < 34000u) {
        uint32_t cur = sio_hw->gpio_hi_in & mask;
        if (cur != prev) { g_tr_st[n] = cur; g_tr_ts[n] = timer_hw->timerawl - t0; n++; prev = cur; }
    }
    restore_interrupts(save);

    printf("trace %lu edges over 34ms (level 1 = released)\n", (unsigned long)n);
    for (uint32_t i = 0; i < n; i++) {
        uint32_t v = g_tr_st[i] >> (PIN_CTRL0 - 32);
        printf("  %6luus TH=%u D3210=%u%u%u%u TL=%u TR=%u\n", (unsigned long)g_tr_ts[i],
               (unsigned)((v >> 2) & 1u), (unsigned)((v >> 6) & 1u), (unsigned)((v >> 5) & 1u),
               (unsigned)((v >> 4) & 1u), (unsigned)((v >> 3) & 1u),
               (unsigned)(v & 1u), (unsigned)((v >> 1) & 1u));
    }
}

// Bench 'r': cable continuity. Fight each port line with our own pull to tell a console pin from an
// open wire; pulls are a pad setting, so a driver's funcsel is untouched.
static void __not_in_flash_func(wire_probe)(void) {
    printf("wire (pd/pu highs per 4096, no buttons held):\n");
    for (uint i = 0; i < PIN_CTRL_N; i++) {
        uint p = PIN_CTRL(i);
        uint32_t bit = 1u << (p - 32), n[2] = { 0, 0 };
        for (int mode = 0; mode < 2; mode++) {
            gpio_set_pulls(p, mode == 1, mode == 0);         // mode 0 = pull-down, 1 = pull-up
            busy_wait_us_32(1000);                           // RC of a weak pull into cable C
            for (int s = 0; s < 4096; s++)
                if (sio_hw->gpio_hi_in & bit) n[mode]++;
        }
        gpio_disable_pulls(p);

        const char *verdict = "?";
        if (n[0] > 4000 && n[1] > 4000)      verdict = "driven/pulled HIGH externally";
        else if (n[0] < 96 && n[1] < 96)     verdict = "driven LOW externally";
        else if (n[0] < 96 && n[1] > 4000)   verdict = "OPEN - nothing on this wire";
        else                                 verdict = "toggling (console is driving it)";
        printf("  GP%u pd=%lu pu=%lu  %s\n", p, (unsigned long)n[0], (unsigned long)n[1], verdict);
    }
}

// Bench 'z': decode one frame the way the console does — sample DATA1 while CLK is low, 16 clocks
// after LATCH. Returns the word with bit n set = pressed, which is what snes_from_pad() produced.
#define SNIFF_TMO_US 50000
#define SNIFF_WAIT(cond)  do { \
        while (cond) if (timer_hw->timerawl - t0 > SNIFF_TMO_US) return false; \
    } while (0)

// Counts every CLK edge, including inside LATCH: counting only after LATCH, as our SM does, would
// hide a shared off-by-one.
#define SNIFF_MAX_CLK 24
typedef struct {
    uint32_t latch_us, first_us, word, word_late;
    uint32_t in_latch, after;
    uint16_t t_us[SNIFF_MAX_CLK];       // each CLK falling edge, relative to LATCH falling
} sniff_t;

static bool __not_in_flash_func(sniff_frame)(sniff_t *r) {
    const uint32_t L = 1u << (PIN_SNES_LATCH - 32);
    const uint32_t C = 1u << (PIN_SNES_CLK   - 32);
    const uint32_t D = 1u << (PIN_SNES_DATA1 - 32);
    uint32_t t0 = timer_hw->timerawl;

    *r = (sniff_t){ 0 };

    SNIFF_WAIT(sio_hw->gpio_hi_in & L);         // land between frames, not mid-pulse
    SNIFF_WAIT(!(sio_hw->gpio_hi_in & L));      // LATCH rises
    uint32_t t_rise = timer_hw->timerawl, prev = sio_hw->gpio_hi_in;

    while (prev & L) {                          // clocks the console issues while LATCH is high
        uint32_t cur = sio_hw->gpio_hi_in;
        if ((prev & C) && !(cur & C)) {
            if (!(cur & D)) r->word |= 1u << r->in_latch;
            r->in_latch++;
        }
        prev = cur;
        if (timer_hw->timerawl - t0 > SNIFF_TMO_US) return false;
    }
    uint32_t t_fall = timer_hw->timerawl;
    r->latch_us = t_fall - t_rise;

    while (!(prev & L)) {                       // ... and every clock up to the next latch
        uint32_t cur = sio_hw->gpio_hi_in;
        if ((prev & C) && !(cur & C)) {
            uint32_t dt = timer_hw->timerawl - t_fall;
            if (!r->after) r->first_us = dt;
            uint32_t n = r->in_latch + r->after;
            if (n < SNIFF_MAX_CLK) r->t_us[n] = (uint16_t)dt;
            // Data changes on CLK rise; resampling 4 us into the 6 us low phase catches a line
            // still slewing.
            if (n < 32 && !(cur & D)) r->word |= 1u << n;
            uint32_t td = timer_hw->timerawl;
            while (timer_hw->timerawl - td < 4u) { }
            cur = sio_hw->gpio_hi_in;
            if (n < 32 && !(cur & D)) r->word_late |= 1u << n;
            r->after++;
        }
        prev = cur;
        if (timer_hw->timerawl - t0 > SNIFF_TMO_US) break;
    }
    return true;
}

static void __not_in_flash_func(ctrl_sniff)(void) {
    sniff_t r[4];
    // A missed edge is a wrong answer here, and a 6 us CLK low phase is shorter than some of
    // core0's ISRs. Capture with interrupts off, print after.
    uint32_t save = save_and_disable_interrupts();
    bool ok = true;
    for (int f = 0; f < 4 && ok; f++) ok = sniff_frame(&r[f]);
    restore_interrupts(save);

    if (!ok) { printf("sniff: timeout (no latch/clock)\n"); return; }
    for (int f = 0; f < 4; f++) {
        printf("sniff latch=%luus in_latch=%lu after=%lu gb=%02x early=%05lx late=%05lx\n",
               (unsigned long)r[f].latch_us, (unsigned long)r[f].in_latch,
               (unsigned long)r[f].after, g_buttons,
               (unsigned long)r[f].word, (unsigned long)r[f].word_late);
        printf("  dt:");
        uint32_t nc = r[f].after < SNIFF_MAX_CLK ? r[f].after : SNIFF_MAX_CLK;
        for (uint32_t i = 0; i < nc; i++)
            printf(" %u", (unsigned)(i ? r[f].t_us[i] - r[f].t_us[i - 1] : r[f].t_us[0]));
        printf("\n");
    }
}
#endif

static inline uint32_t mbox_index(uint32_t cap) {      // A0-A2, un-permuted
    uint32_t n = 0;
    for (int i = 0; i < 3; i++) { n |= ((cap >> cs_wire_pos[i]) & 1U) << i; }
    return n;
}

static void mbox_write(uint32_t reg, uint8_t v) {
    g_mbox_writes++;
    switch (reg) {
    case MBOX_BTN:     g_buttons = v; g_btn_seq++; g_btn_pending = true; break;
    case MBOX_MODE:    g_mode = v;                  break;
    case MBOX_CFG_IDX: g_cfg_idx = v;               break;
    case MBOX_CFG_VAL:
        g_config[g_cfg_idx] = v;
        // cfg_drv_block() honors the CFG_DRV block only for its stamped owner, so a protocol
        // change invalidates it for free.
        if (g_cfg_idx > CFG_DRV_OWNER) { g_config[CFG_DRV_OWNER] = cfg_proto_sel(g_config); }
        g_cfg_dirty = true;
        g_cfg_class = cfg_class_of(g_cfg_idx);
        break;
    case MBOX_COMMIT:  g_commit_req = true;         break;
    default: break;
    }
}
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
int main(void) {
    // Hold the console before anything else can fail. The pad default already holds it via the
    // gate pull-up; this makes it explicit and independent of the pad reset state.
    cs_rsthold_assert();
    // Before anything that can fail. The port can source 5 V and a driven pin into an unknown
    // cable is not something to leave to the pad reset state.
    ctrl_init_safe();

    cs_set_operating_point();

    cs_rsthold_arm_failsafe();

    cs_bus_priority();

    // UART1 on GP40/GP5 (J4), plus a CDC on J2 when USB_CONSOLE is on.
    stdio_init_all();

    // Probed only for the boot log. After the final clock (timing derives from clk_sys), before core1
    // and the serve PIO (its QMI direct mode takes XIP away).
    g_ps_size = (uint32_t)psram_init(PSRAM_CS_PIN);

    config_load();
#ifdef BENCH_PROTO
    g_config[CFG_PROTO_SEL] = BENCH_PROTO;   // bench build: no GB to write $6002/$6003
#endif
    cable_id_init();
    romstore_init();
    vmu_store_init();               // before the console runs: dc_init() serves whatever it loaded
    vmu_run_init();                 // after it: the emulated card runs whatever the slot held
    romstore_config(g_config);
    drv_init_core0(g_config);
    for (unsigned b = 0; b < GB_ROM_BANKS; b++) {
        g_bank_ptr[b] = b < 2 ? cs_bank((int)b) : g_banks[b - 2];
        cs_load(g_bank_ptr[b], gb_rom[b], 0x4000);
    }
    vmu_fb_init();                          // after the high bank is loaded: it clones it
    padart_init();                          // ... and after that clone, or it captures a stale bank
    cs_seed(STATUS_ADDR, g_status);
    cs_seed(VERSION_ADDR, FW_VERSION);
    cs_seed(VMU_SEQ_ADDR, 0);
    cs_seed(VMU_STAT_ADDR, g_vmu_stat);     // unseeded these read $FF, i.e. dirty and saving
    cs_seed(VMU_SAVES_ADDR, 0);
    for (uint32_t i = 0; i < CFG_LEN; i++) { cs_seed(CFG_MIRROR + i, g_config[i]); }
    static uint8_t cat[CAT_PAGE_LEN];
    pad_catalog_build(cat, pad_driver_table(), pad_driver_count());
    for (uint32_t i = 0; i < CAT_PAGE_LEN; i++) { cs_seed(CATALOG_ADDR + i, cat[i]); }
    static uint8_t mpi[PMI_LEN];
    pad_mapinfo_build(mpi, pad_driver_table(), pad_driver_count());
    for (uint32_t i = 0; i < PMI_LEN; i++) { cs_seed(PMI_ADDR + i, mpi[i]); }
    static uint8_t slots[SLOT_PAGE_LEN];
    romstore_build_page(slots);
    for (uint32_t i = 0; i < SLOT_PAGE_LEN; i++) { cs_seed(SLOT_PAGE_ADDR + i, slots[i]); }

    cs_start();
    cs_mbc_start(g_bank_ptr, GB_ROM_BANKS);        // after cs_start(), which resets the bases

    cs_rsthold_release();                          // bus is answering; let the console run

    // After the release: no driver init can eat into the boot-race budget, and a hung driver
    // costs a dead controller port, never a dead console.
    drv_start();

    run_bus();
}

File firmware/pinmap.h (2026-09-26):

// pinmap.h — RP2350B (U1) GPIOs to cart edge J1 and controller port J3; check_sch.py diffs it
// against hardware/gen/expected_nets.txt. The cart bus stays at GP31 and below: one 32-bit mask.
#pragma once

#define PIN_RSTHOLD 0   // gate of the /RST hold FET        — output; HIGH = console held in reset
#define PIN_CLK   1     // GB CLK (timing reference)        — input
#define PIN_NWR   2     // GB /WR                           — input
#define PIN_NRD   3     // GB /RD  (read=low, write=high)   — input
#define PIN_NCS   4     // GB /CS                           — input (unused for ROM)
#define PIN_A14   6     // A14 — region gate (low/high bank)
#define PIN_A15   7     // A15 — internal-space gate ($8000+)
#define PIN_D0    8     // D0..D7 = GP8..GP15 (D0 = LSB)    — driven on reads
#define PIN_RST   16    // GB /reset                        — input; resets cart state
#define PIN_A0    18    // A0..A13 = GP18..GP31             — input

// wire_pos[i] = offset from PIN_A0 of the GPIO carrying A(i); the first suspect for a garbled logo.
// Banks are permuted at load; the mailbox paths un-permute via cs_wire_pos.
#define A0_13_WIRE_POS { 0, 1, 2, 3, 4, 5, 6, 7, 8, 9, 10, 11, 12, 13 }

// write_capture samples GP17 into bit 11, which nothing reads; the GP16/GP17 gap puts A0 at bit 12.

// Controller port CTRL0-7 = GP32-39, each behind 100R (R16-R23); reachable only from PIO2 at base 16.
#define PIN_CTRL0    32
#define PIN_CTRL_N   8
#define PIN_CTRL(n)  (PIN_CTRL0 + (n))

#define PIN_JOYBUS   PIN_CTRL0      // N64 Joybus data line

// Dreamcast Maple. Must be consecutive with SDCKA lower: the PIO reaches both with one
// `set pins,2`, and the decode reads them as bit0=SDCKA, bit1=SDCKB.
#define PIN_MAPLE_A  PIN_CTRL0      // DC connector pin 1
#define PIN_MAPLE_B  PIN_CTRL(1)    // DC connector pin 5

// SNES/NES. LATCH and CLK consecutive, LATCH lower: one IN base reaches both. DATA1 is the only
// driven line, open-drain.
#define PIN_SNES_DATA1  PIN_CTRL0   // SNES connector pin 4 / NES D0
#define PIN_SNES_DATA2  PIN_CTRL(1) // SNES pin 5 — fitted, outside ctrl_mask: Hi-Z reads as no joypad 3
#define PIN_SNES_LATCH  PIN_CTRL(2) // SNES pin 3
#define PIN_SNES_CLK    PIN_CTRL(3) // SNES pin 2
#define PIN_SNES_IOBIT  PIN_CTRL(4) // SNES pin 6 — fitted, outside ctrl_mask, reserved

// Genesis / Mega Drive DE-9. Seven signals, CTRL7 left free. Two adjacency rules, one per state
// machine: D0-D3 must be consecutive for `out pindirs,4` and TL/TR consecutive for `out pindirs,2`.
#define PIN_GEN_TL   PIN_CTRL0      // DB9 pin 6 — D4: B while TH high, A while low
#define PIN_GEN_TR   PIN_CTRL(1)    // DB9 pin 9 — D5: C while TH high, START while low
#define PIN_GEN_TH   PIN_CTRL(2)    // DB9 pin 7 — console output. `wait n pin 0` and `jmp pin`
#define PIN_GEN_D0   PIN_CTRL(3)    // D0-D3 = DB9 1-4: UP/DOWN/LEFT/RIGHT, or Z/Y/X/MODE on cycle 7

#define PIN_CTRL_ID  41             // cable ID divider: R24 10k to +3V3, R_id in the adapter shell
#define CTRL_ID_ADC  1              // ADC input 1 (RP2350B: ADC0..7 = GP40..47)

#define PIN_BLE_EN   17             // U6 load switch on the RM2's 3V3; R32 holds it off on a cold board

#define PIN_IR_TX    46             // IR_DRIVE: high turns Q on and lights the LED; R27 holds it off

// Also taken, no pin spare: GP5/GP40 UART1 (J4), GP42-45 RM2 gSPI, GP47 PSRAM CS (U3).

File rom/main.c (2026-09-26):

// main.c — the GB-side half of the controller cart.
//
// A menu app. The firmware serves this as a static 32 KB ROM and rewrites bytes of it under us;
// mbox.h names every one of them. The root menu's Controllers section renders the driver catalog
// the firmware publishes at $0300, so a driver added to k_drivers[] appears here with no change
// to this ROM.
//
// SINGLE SPEED ONLY — never call cpu_fast(). The capture bench measured the serve path arriving
// one byte late in double speed at 150, 200 and 250 MHz: the first fetch after the switch executes
// $FF and the console sits in an rst $38 loop forever.
#include <gb/gb.h>
#include <gb/cgb.h>
#include <gbdk/console.h>
#include <stdint.h>
#include "screens.h"
#include "mbox.h"
#include "theme.h"

void main(void)
{
    // M_NO_SCROLL matters: a console scroll is a full-screen VRAM copy that would run outside
    // VBlank. The screens draw through canvas.c; the console is only cls() and the font.
    mode(M_TEXT_OUT | M_NO_SCROLL | M_NO_INTERP);
    th_init();

    MBOX_MODE = MODE_CONFIG;
    MBOX_BTN  = 0;

    ui_run(&scr_root);
}

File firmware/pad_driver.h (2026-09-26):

// pad_driver.h — the controller-protocol driver interface.
#ifndef PAD_DRIVER_H
#define PAD_DRIVER_H

#include <stdint.h>
#include <stdbool.h>
#include "pad.h"

typedef enum {
    PAD_OK              =  0,
    PAD_ERR_NO_RESOURCE = -1,   // PIO words, SMs or DMA channels unavailable
    PAD_ERR_UNSAFE      = -2,   // ctrl_claim() refused the pins
    PAD_ERR_CONFIG      = -3,
    PAD_ERR_HW          = -4,
} pad_err_t;

// Stored in g_config[CFG_PROTO_SEL]; never renumber.
enum {
    PROTO_NONE      = 0,
    PROTO_N64       = 1,
    PROTO_SNES      = 2,
    PROTO_NES       = 3,
    PROTO_GENESIS   = 4,
    PROTO_DREAMCAST = 5,
    PROTO_FAMICOM   = 6,
    PROTO_LOOPY     = 7,
    PROTO_GCV2      = 8,
    PROTO_SNES_MOUSE = 9,
    PROTO_USB_HID   = 16,       // pinless transports share the vtable: ctrl_mask == 0
    PROTO_BLE_HID   = 17,
    PROTO_VIS       = 18,       // the Tandy VIS controller, out of the cart's own IR LED on GP46
};

// Every proto from here up needs no adapter cable, so a plugged-in cable never overrides it.
// drv_apply() refuses a driver whose ctrl_mask disagrees with its number.
#define PROTO_PINLESS_FIRST PROTO_USB_HID
static inline bool proto_pinless(uint8_t p) { return p >= PROTO_PINLESS_FIRST && p != 0xff; }

// Declared statically so drv_check() can refuse a driver before init() touches a pin.
typedef struct {
    uint8_t ctrl_mask;          // bit n: CTRLn (GP32+n) is used
    uint8_t ctrl_out_mask;      // subset of ctrl_mask that is ever driven
    uint8_t pio_sms;
    uint8_t pio_words;
    uint8_t dma_chans;
    uint8_t logic_5v : 1;       // signal lines are 5 V (informational, published as CATF_LOGIC_5V)
    uint8_t needs_5v : 1;       // target sources CTRL_5V
    // Spends the gSPI's PIO2 reservation; legal only because PROTO_BLE_HID can never be co-resident.
    uint8_t excl_ble : 1;
} pad_res_t;

// One entry of the GB mapping menu: a config_map.h pad_action byte, in the target console's words.
typedef struct {
    uint8_t     action;
    const char *label;          // <= PMI_LABEL_LEN chars
} pad_target_t;

#define PAD_TARGETS(t) .targets = (t), .ntargets = sizeof (t) / sizeof *(t)

// The shared rows of a target table; ACT_* come from config_map.h.
#define PT_DPAD  { ACT_PAD(PAD_UP), "Up" },   { ACT_PAD(PAD_DOWN), "Down" }, \
                 { ACT_PAD(PAD_LEFT), "Left" }, { ACT_PAD(PAD_RIGHT), "Right" }
#define PT_STICK { ACT_AXIS(AX_LY, 1), "Stick U" }, { ACT_AXIS(AX_LY, 0), "Stick D" }, \
                 { ACT_AXIS(AX_LX, 0), "Stick L" }, { ACT_AXIS(AX_LX, 1), "Stick R" }

typedef struct pad_driver pad_driver_t;

struct pad_driver {
    const char *name;           // log token, printed as drv=%s in the telemetry line
    const char *label;          // menu label for the published catalog, <= 13 chars. NULL => name.
    uint8_t     proto;
    pad_res_t   res;
    const pad_target_t *targets;    // what the projection consumes; NULL => the eight GB buttons
    uint8_t             ntargets;

    // init/deinit install and remove any IRQ handler or alarm pool: irq_set_enabled() is per-core.
    pad_err_t (*init)    (const pad_driver_t *d, const uint8_t *drv_cfg);
    void      (*deinit)  (const pad_driver_t *d);
    // May spin inside one protocol frame; returns after at most idle_us with no traffic.
    void      (*service) (const pad_driver_t *d, const pad_state_t *s, uint32_t idle_us);
    pad_err_t (*reconfig)(const pad_driver_t *d, const uint8_t *drv_cfg);
    bool      (*link_up) (const pad_driver_t *d);   // end-to-end: the console addressed us recently
};

// PIO2 held back for the CYW43 gSPI; the declared budget, pio_can_add_program() is still the real gate.
#define PIO2_RESERVED_WORDS 6
#define PIO2_RESERVED_SMS   1

#define PAD_LINK_MS 250

// A link_up() verdict: the console addressed us within PAD_LINK_MS. last_ms 0 means never.
static inline bool pad_link_recent(uint32_t last_ms, uint32_t now_ms) {
    return last_ms && (now_ms - last_ms) < PAD_LINK_MS;
}

// The one static resource verdict: the catalog and drv_check() both call it, so they cannot disagree.
pad_err_t pad_res_check(const pad_res_t *r);

const pad_driver_t *pad_driver_for(uint8_t proto);

// For the $0300 catalog; k_drivers[] is const, so fixed for the run.
unsigned                   pad_driver_count(void);
const pad_driver_t *const *pad_driver_table(void);

#endif

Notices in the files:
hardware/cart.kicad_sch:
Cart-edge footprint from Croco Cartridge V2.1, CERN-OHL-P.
